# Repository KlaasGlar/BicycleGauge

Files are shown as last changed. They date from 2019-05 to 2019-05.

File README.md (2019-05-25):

# BicycleGauge

## Introduction

This project features an advanced computer for use on bicycles.
A microcontroller reads sensor data and sends it to a smartphone via bluetooth.

## Feature list

The following features are going to be integrated in the prototype:
- Magnetic switch for reading the revolution speed of the pedals
- Magnetic switch at the back wheel for reading the absolute speed
- Solar cell for recharging the computer's battery (Li-Ion AAA battery)
- Bluetooth module for communication with the smartphone
- Magnetic sensor for the reading the earth's magnetic field to calculate the slope when going up/downhill
- Analog sensor to read the battery charge status
- All parts are going to be waterproofed for outdoor use

## Content of this repository

The repository contains the following things:
- Schematic and PCB data for the main PCB
- Schematic and PCB data for the magnetic switches
- ~~CAD data for the housing of the main PCB~~
- ~~Code for programming the microcontroller~~
- ~~Code for the Android App to connect to the computer~~

**_The project is currently in development. New things are added little by little.
My plan is to have the prototype running by end of July 2019.
See the roadmap below for the current status._**

## Roadmap

- [X] <code>[##########>]&nbsp;100%</code> Creating the schematics for the main PCB
- [X] <code>[##########>]&nbsp;100%</code> Designing the main PCB
- [X] <code>[##########>]&nbsp;100%</code> Creating the schematics for the magnetic switches
- [X] <code>[##########>]&nbsp;100%</code> Designing the PCB for the magnetic switches
- [ ] <code>[###>_______]&nbsp;&nbsp;30%</code> Designing the housing (CAD)
- [ ] <code>[>__________]&nbsp;&nbsp;&nbsp;0%</code> Programming the microcontroller
- [ ] <code>[#>_________]&nbsp;&nbsp;10%</code> Programming the Android app

## Future ideas

- Voltage / current sensor to measure the power generated by the solar cell
- Smaller Battery if overall power consumption is measured to be sufficiently low

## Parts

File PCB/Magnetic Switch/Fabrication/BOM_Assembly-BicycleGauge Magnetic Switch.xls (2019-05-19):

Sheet: Assembly
ASSEMBLY |  |  |  |  |  | v1.0
 |  |  |  |  |  | 19.05.2019
 |  |  |  |  |  | 10:40:14
 |  |  | Bicycle Gauge Magnetic Switch
 | Project |  | BicycleGauge Magnetic Switch.PrjPcb
 | Drawn By |  | Sven Möller
 | Approved By |  | -
# |  | Quantity | Description | MPN | Designator
1 | ¨ | 1 | Diode, TVS, 3.3V, 4 Channel | 824013 | D1
2 | ¨ | 1 | Magnetic Sensor, SOT-23, Hall-Effect 3mT, Open-Drain, 2.5-5.5V | AH1806-W-7 | IC1
3 | ¨ | 2 | Connector, PTSM, SMD, 4 pol., Wire to Board | 1702474 | J1, J2

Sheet: Haken
¨
þ

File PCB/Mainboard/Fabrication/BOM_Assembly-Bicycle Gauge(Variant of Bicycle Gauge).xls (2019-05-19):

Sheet: Assembly
ASSEMBLY |  |  |  |  |  | v1.0.1
 |  |  |  |  |  | 19.05.2019
 |  |  |  |  |  | 10:30:37
 |  |  | Bicycle Gauge
 | Project |  | Bicycle Gauge.PrjPcb
 | Drawn By |  | Sven Möller
 | Approved By |  | -
# |  | Quantity | Description | MPN | Designator
1 | ¨ | 1 | Bluetooth module, Proteus-I, BT 4.2, AMB2621 | 2608011024000 | B1
2 | ¨ | 6 | Cap, 100n, 0603, X7R, 50V | CC0603KRX7R9BB104 | C1, C3, C6, C7, C16A, C16B
3 | ¨ | 1 | Cap, 1µ, 4x5.4mm, Aluminum Electrolyte, 35V | EEE-FC1V1R0R | C4
4 | ¨ | 2 | Cap, 18p, 0603, C0G, 50V | C0603C180J5GACTU | C8, C9
5 | ¨ | 2 | Cap, 1µ, 0805, 50V, X7R | GRM21BR71H105KA12L | C10, C11
6 | ¨ | 2 | Cap, 4.7µ, 0603, X5R, 10V | C0603C475M8PACTU | C12, C14
7 | ¨ | 2 | Cap, 10n, 0603, C0G, 25V | C0603C103J3GACTU | C13, C15
8 | ¨ | 1 | Diode, TVS, 3.3V, 4 Channel | 824013 | D1
9 | ¨ | 1 | MCU, TQFP-32, AVR-Mega 8-bit, 1.8-5.5V | ATmega328PB-AU | IC1
10 | ¨ | 1 | Magnetic Sensor, LGA-12, 1.9-3.6V, +/-1.6mT | LIS3MDLTR | IC2
11 | ¨ | 1 | Linear Regulator, SOT-23-5, 2.7V, Input 2.2-5.5V | TPS78227DDCR | IC3
12 | ¨ | 2 | MOSFET, SOT-883, p-channel, -20V, -0.5A, low leakage current | PMZ950UPEL | IC4, IC5
13 | ¨ | 1 | Energy Harvester / Boost Converter, VQFN-20 | BQ25505RGRR | IC6
14 | ¨ | 2 | Op-Amp, SOT-32, 1.7-5.5V, Rail-to-rail, Nanopower | OPA322SAIDBVR | IC7A, IC7B
15 | ¨ | 2 | MOSFET, SOT-883, n-channel, 20V, 0.6A, low leakage current | PMZ600UNEL | IC8A, IC8B
16 | ¨ | 1 | Connector, M8, SMD, 4-pin, Female | 1412228 | J1
17 | ¨ | 1 | Connector, PTSM, SMD, 2 pol., Wire to board | 1702473 | J2
18 | ¨ | 1 | Ind, 22µH, 0.51A, 3.8x3.8x1.65mm | 744031220 | L1
19 | ¨ | 2 | Res, 10R, 0603, 1%, 100mW, 50V | ERJ-3EKF10R0V | R1, R2
20 | ¨ | 7 | Res, 698k, 0603, 1%, 75V, 100mW | ERJ-3EKF6983V | R3, R4, R5, R10, R15A, R15B, R16
21 | ¨ | 1 | Res, 7.32M, 0603, 1%, 75V, 100mW | CRCW06037M32FKEA | R6
22 | ¨ | 2 | Res, 1.3M, 0603, 1%, 75V, 100mW | CRCW06031M30FKEA | R7, R12
23 | ¨ | 1 | Res, 5.62M, 0603, 1%, 75V, 100mW | CRCW06035M62FKEA | R8
24 | ¨ | 1 | Res, 6.98M, 0603, 1%, 75V, 100mW | CRCW06036M98FKEA | R9
25 | ¨ | 1 | Res, 4.7M, 0603, 1%, 75V, 100mW | CRCW06034M70FKEA | R11
26 | ¨ | 4 | Res, 330k, 0603, 0.1%, 25ppm, 75V, 100mW | ERA-3AEB334V | R13A, R13B, R14A, R14B
27 | ¨ | 1 | Housing, Panelmount, M8, Female | 1412504 | X1
28 | ¨ | 1 | Switch, SMD, DPDT, Slider WS-SLSV | 452403012014 | X2
29 | ¨ | 1 | Battery Holder, THT, 1xAAA | 1021 | X4
30 | ¨ | 1 | Solar Cell, 39.8mA@2.2V, 3.4V, 50x33x1.8mm | AM-5412CAR | X5
31 | ¨ | 1 | Nut, M10 | 1412508 | X6
32 | ¨ | 1 | Crystal, SMD, 7.3728MHz, 18pF | ABMM2-7.3728MHZ-E2-T | XT1

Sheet: Haken
¨
þ

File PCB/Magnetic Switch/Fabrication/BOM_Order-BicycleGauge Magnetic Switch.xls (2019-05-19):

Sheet: BOM
BILL OF MATERIALS |  |  |  |  |  |  |  | v1.0
 |  |  |  |  |  |  |  | 19.05.2019
 |  |  |  |  |  |  |  | 10:40:06
 |  |  | Bicycle Gauge Magnetic Switch
 | Project |  | BicycleGauge Magnetic Switch.PrjPcb |  |  | Production Quantity | 2
 | Drawn By |  | Sven Möller
 | Approved By |  | -
# |  | Qty | Description | Manufacturer | MPN | Digi-Key | Stock | Price | Farnell | Stock | Price | Mouser | Stock | Price | Supplier 4 | Supplier Part Number 4 | Stock | Price
1 | ¨ | 2 | Diode, TVS, 3.3V, 4 Channel | Würth Electronics | 824013 | 732-4466-1-ND | 23680 | 1.20 | 1825869 | 6162 | 0.00 | 710-824013 | 14221 | 1.20 | RSComponents | 7546222 | 585 | 0.00
2 | ¨ | 2 | Magnetic Sensor, SOT-23, Hall-Effect 3mT, Open-Drain, 2.5-5.5V | Diodes Inc. | AH1806-W-7 | AH1806-W-7DICT-ND | 26504 | 0.49 | - | 0 | 0.00 | 621-AH1806-W-7 | 43782 | 0.44 |  |  | 0 | 0.00
3 | ¨ | 4 | Connector, PTSM, SMD, 4 pol., Wire to Board | Phoenix Contact | 1702474 | 277-2338-1-ND | 1322 | 1.06 | - | 0 | 0.00 | 651-1702474 | 1334 | 1.07 | RSComponents | 804-5449 | 0 | 0.00

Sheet: Haken
¨ | #REF! | #REF!
þ | #REF! | #REF!
yes | #REF! | #REF!
no | #REF! | #REF!
 | #REF! | #REF!
 | #REF! | #REF!
 | #REF! | #REF!
 | #REF! | #REF!
 | #REF! | #REF!
 | #REF! | #REF!
 | #REF! | #REF!
 | #REF! | #REF!
 | #REF! | #REF!
 | #REF! | #REF!
 | #REF! | #REF!
 | #REF! | #REF!
 | #REF! | #REF!
 | #REF! | #REF!
 | #REF! | #REF!
 | #REF! | #REF!
 | #REF! | #REF!
 | #REF! | #REF!
 | #REF! | #REF!
 | #REF! | #REF!
 | #REF! | #REF!
 | #REF! | #REF!
 | #REF! | #REF!
 | #REF! | #REF!
 | #REF! | #REF!
 | #REF! | #REF!
 | #REF! | #REF!
 | #REF! | #REF!
 | #REF! | #REF!
 | #REF! | #REF!
 | #REF! | #REF!
 | #REF! | #REF!
 | #REF! | #REF!
 | #REF! | #REF!
 | #REF! | #REF!
 | #REF! | #REF!
 | #REF! | #REF!
 | #REF! | #REF!
 | #REF! | #REF!
 | #REF! | #REF!
 | #REF! | #REF!
 | #REF! | #REF!
 | #REF! | #REF!
 | #REF! | #REF!
 | #REF! | #REF!
 | #REF! | #REF!
 | #REF! | #REF!
 | #REF! | #REF!
 | #REF! | #REF!
 | #REF! | #REF!
 | #REF! | #REF!
 | #REF! | #REF!
 | #REF! | #REF!
 | #REF! | #REF!
 | #REF! | #REF!
 | #REF! | #REF!
 | #REF! | #REF!
 | #REF! | #REF!
 | #REF! | #REF!
 | #REF! | #REF!
 | #REF! | #REF!
 | #REF! | #REF!
 | #REF! | #REF!
 | #REF! | #REF!
 | #REF! | #REF!
 | #REF! | #REF!
 | #REF! | #REF!
 | #REF! | #REF!
 | #REF! | #REF!
 | #REF! | #REF!
 | #REF! | #REF!
 | #REF! | #REF!
 | #REF! | #REF!
 | #REF! | #REF!
 | #REF! | #REF!
 | #REF! | #REF!
 | #REF! | #REF!
 | #REF! | #REF!
 | #REF! | #REF!
 | #REF! | #REF!
 | #REF! | #REF!
 | #REF! | #REF!
 | #REF! | #REF!
 | #REF! | #REF!
 | #REF! | #REF!
 | #REF! | #REF!
 | #REF! | #REF!
 | #REF! | #REF!
 | #REF! | #REF!
 | #REF! | #REF!
 | #REF! | #REF!
 | #REF! | #REF!
 | #REF! | #REF!
 | #REF! | #REF!
 | #REF! | #REF!
 | #REF! | #REF!
 | #REF! | #REF!
 | #REF! | #REF!
 | #REF! | #REF!
 | #REF! | #REF!
 | #REF! | #REF!
 | #REF! | #REF!
 | #REF! | #REF!
 | #REF! | #REF!
 | #REF! | #REF!
 | #REF! | #REF!
 | #REF! | #REF!
 | #REF! | #REF!
 | #REF! | #REF!
 | #REF! | #REF!
 | #REF! | #REF!
 | #REF! | #REF!
 | #REF! | #REF!
 | #REF! | #REF!
 | #REF! | #REF!
 | #REF! | #REF!
 | #REF! | #REF!
 | #REF! | #REF!
 | #REF! | #REF!
 | #REF! | #REF!
 | #REF! | #REF!
 | #REF! | #REF!
 | #REF! | #REF!
 | #REF! | #REF!
 | #REF! | #REF!
 | #REF! | #REF!
 | #REF! | #REF!
 | #REF! | #REF!
 | #REF! | #REF!
 | #REF! | #REF!
 | #REF! | #REF!
 | #REF! | #REF!
 | #REF! | #REF!
 | #REF! | #REF!
 | #REF! | #REF!
 | #REF! | #REF!
 | #REF! | #REF!
 | #REF! | #REF!
 | #REF! | #REF!
 | #REF! | #REF!
 | #REF! | #REF!
 | #REF! | #REF!
 | #REF! | #REF!
 | #REF! | #REF!
 | #REF! | #REF!
 | #REF! | #REF!
 | #REF! | #REF!
 | #REF! | #REF!
 | #REF! | #REF!
 | #REF! | #REF!
 | #REF! | #REF!
 | #REF! | #REF!
 | #REF! | #REF!
 | #REF! | #REF!
 | #REF! | #REF!
 | #REF! | #REF!
 | #REF! | #REF!
 | #REF! | #REF!
 | #REF! | #REF!
 | #REF! | #REF!
 | #REF! | #REF!
 | #REF! | #REF!
 | #REF! | #REF!
 | #REF! | #REF!
 | #REF! | #REF!
 | #REF! | #REF!
 | #REF! | #REF!
 | #REF! | #REF!
 | #REF! | #REF!
 | #REF! | #REF!
 | #REF! | #REF!
 | #REF! | #REF!
 | #REF! | #REF!
 | #REF! | #REF!
 | #REF! | #REF!
 | #REF! | #REF!
 | #REF! | #REF!
 | #REF! | #REF!
 | #REF! | #REF!
 | #REF! | #REF!
 | #REF! | #REF!
 | #REF! | #REF!
 | #REF! | #REF!
 | #REF! | #REF!
 | #REF! | #REF!
 | #REF! | #REF!
 | #REF! | #REF!
 | #REF! | #REF!
 | #REF! | #REF!
 | #REF! | #REF!
 | #REF! | #REF!
 | #REF! | #REF!
 | #REF! | #REF!
 | #REF! | #REF!
 | #REF! | #REF!
 | #REF! | #REF!
 | #REF! | #REF!
 | #REF! | #REF!
 | #REF! | #REF!
 | #REF! | #REF!
 | #REF! | #REF!
 | #REF! | #REF!
 | #REF! | #REF!
 | #REF! | #REF!
 | #REF! | #REF!
 | #REF! | #REF!
 | #REF! | #REF!
 | #REF! | #REF!
 | #REF! | #REF!
 | #REF! | #REF!
 | #REF! | #REF!
 | #REF! | #REF!
 | #REF! | #REF!
 | #REF! | #REF!
 | #REF! | #REF!
 | #REF! | #REF!
 | #REF! | #REF!
 | #REF! | #REF!
 | #REF! | #REF!
 | #REF! | #REF!
 | #REF! | #REF!
 | #REF! | #REF!
 | #REF! | #REF!
 | #REF! | #REF!
 | #REF! | #REF!
 | #REF! | #REF!
 | #REF! | #REF!
 | #REF! | #REF!
 | #REF! | #REF!
 | #REF! | #REF!
 | #REF! | #REF!
 | #REF! | #REF!
 | #REF! | #REF!
 | #REF! | #REF!
 | #REF! | #REF!
 | #REF! | #REF!
 | #REF! | #REF!
 | #REF! | #REF!
 | #REF! | #REF!
 | #REF! | #REF!
 | #REF! | #REF!
 | #REF! | #REF!
 | #REF! | #REF!
 | #REF! | #REF!
 | #REF! | #REF!
 | #REF! | #REF!
 | #REF! | #REF!
 | #REF! | #REF!
 | #REF! | #REF!
 | #REF! | #REF!
 | #REF! | #REF!
 | #REF! | #REF!
 | #REF! | #REF!
 | #REF! | #REF!
 | #REF! | #REF!
 | #REF! | #REF!
 | #REF! | #REF!
 | #REF! | #REF!
 | #REF! | #REF!
 | #REF! | #REF!
 | #REF! | #REF!
 | #REF! | #REF!
 | #REF! | #REF!
 | #REF! | #REF!
 | #REF! | #REF!
 | #REF! | #REF!
 | #REF! | #REF!
 | #REF! | #REF!
 | #REF! | #REF!
 | #REF! | #REF!
 | #REF! | #REF!
 | #REF! | #REF!
 | #REF! | #REF!
 | #REF! | #REF!
 | #REF! | #REF!
 | #REF! | #REF!
 | #REF! | #REF!
 | #REF! | #REF!
 | #REF! | #REF!
 | #REF! | #REF!
 | #REF! | #REF!
 | #REF! | #REF!
 | #REF! | #REF!
 | #REF! | #REF!
 | #REF! | #REF!
 | #REF! | #REF!
 | #REF! | #REF!
 | #REF! | #REF!
 | #REF! | #REF!
 | #REF! | #REF!
 | #REF! | #REF!
 | #REF! | #REF!
 | #REF! | #REF!
 | #REF! | #REF!
 | #REF! | #REF!
 | #REF! | #REF!
 | #REF! | #REF!
 | #REF! | #REF!
 | #REF! | #REF!
 | #REF! | #REF!
 | #REF! | #REF!
 | #REF! | #REF!
 | #REF! | #REF!
 | #REF! | #REF!
 | #REF! | #REF!
 | #REF! | #REF!
 | #REF! | #REF!
 | #REF! | #REF!
 | #REF! | #REF!
 | #REF! | #REF!
 | #REF! | #REF!
 | #REF! | #REF!
 | #REF! | #REF!
 | #REF! | #REF!
 | #REF! | #REF!
 | #REF! | #REF!
 | #REF! | #REF!
 | #REF! | #REF!
 | #REF! | #REF!
 | #REF! | #REF!
 | #REF! | #REF!
 | #REF! | #REF!
 | #REF! | #REF!
 | #REF! | #REF!
 | #REF! | #REF!
 | #REF! | #REF!
 | #REF! | #REF!
 | #REF! | #REF!
 | #REF! | #REF!
 | #REF! | #REF!
 | #REF! | #REF!
 | #REF! | #REF!
 | #REF! | #REF!
 | #REF! | #REF!
 | #REF! | #REF!
 | #REF! | #REF!
 | #REF! | #REF!
 | #REF! | #REF!
 | #REF! | #REF!
 | #REF! | #REF!
 | #REF! | #REF!
 | #REF! | #REF!
 | #REF! | #REF!
 | #REF! | #REF!
 | #REF! | #REF!
 | #REF! | #REF!
 | #REF! | #REF!
 | #REF! | #REF!
 | #REF! | #REF!
 | #REF! | #REF!
 | #REF! | #REF!
 | #REF! | #REF!
 | #REF! | #REF!
 | #REF! | #REF!
 | #REF! | #REF!
 | #REF! | #REF!
 | #REF! | #REF!
 | #REF! | #REF!
 | #REF! | #REF!
 | #REF! | #REF!
 | #REF! | #REF!
 | #REF! | #REF!
 | #REF! | #REF!
 | #REF! | #REF!
 | #REF! | #REF!
 | #REF! | #REF!
 | #REF! | #REF!
 | #REF! | #REF!
 | #REF! | #REF!
 | #REF! | #REF!
 | #REF! | #REF!
 | #REF! | #REF!
 | #REF! | #REF!
 | #REF! | #REF!
 | #REF! | #REF!
 | #REF! | #REF!
 | #REF! | #REF!
 | #REF! | #REF!
 | #REF! | #REF!
 | #REF! | #REF!
 | #REF! | #REF!
 | #REF! | #REF!
 | #REF! | #REF!
 | #REF! | #REF!
 | #REF! | #REF!
 | #REF! | #REF!
 | #REF! | #REF!
 | #REF! | #REF!
 | #REF! | #REF!
 | #REF! | #REF!
 | #REF! | #REF!
 | #REF! | #REF!
 | #REF! | #REF!
 | #REF! | #REF!
 | #REF! | #REF!
 | #REF! | #REF!
 | #REF! | #REF!
 | #REF! | #REF!
 | #REF! | #REF!
 | #REF! | #REF!
 | #REF! | #REF!
 | #REF! | #REF!
 | #REF! | #REF!
 | #REF! | #REF!
 | #REF! | #REF!
 | #REF! | #REF!
 | #REF! | #REF!
 | #REF! | #REF!
 | #REF! | #REF!
 | #REF! | #REF!
 | #REF! | #REF!
 | #REF! | #REF!
 | #REF! | #REF!
 | #REF! | #REF!
 | #REF! | #REF!
 | #REF! | #REF!
 | #REF! | #REF!
 | #REF! | #REF!
 | #REF! | #REF!
 | #REF! | #REF!
 | #REF! | #REF!
 | #REF! | #REF!
 | #REF! | #REF!
 | #REF! | #REF!
 | #REF! | #REF!
 | #REF! | #REF!
 | #REF! | #REF!
 | #REF! | #REF!
 | #REF! | #REF!
 | #REF! | #REF!
 | #REF! | #REF!
 | #REF! | #REF!
 | #REF! | #REF!
 | #REF! | #REF!
 | #REF! | #REF!
 | #REF! | #REF!
 | #REF! | #REF!
 | #REF! | #REF!
 | #REF! | #REF!
 | #REF! | #REF!
 | #REF! | #REF!
 | #REF! | #REF!
 | #REF! | #REF!
 | #REF! | #REF!
 | #REF! | #REF!
 | #REF! | #REF!
 | #REF! | #REF!
 | #REF! | #REF!
 | #REF! | #REF!
 | #REF! | #REF!
 | #REF! | #REF!
 | #REF! | #REF!
 | #REF! | #REF!
 | #REF! | #REF!
 | #REF! | #REF!
 | #REF! | #REF!
 | #REF! | #REF!
 | #REF! | #REF!
 | #REF! | #REF!
 | #REF! | #REF!
 | #REF! | #REF!
 | #REF! | #REF!
 | #REF! | #REF!
 | #REF! | #REF!
 | #REF! | #REF!
 | #REF! | #REF!
 | #REF! | #REF!
 | #REF! | #REF!
 | #REF! | #REF!
 | #REF! | #REF!
 | #REF! | #REF!
 | #REF! | #REF!
 | #REF! | #REF!
 | #REF! | #REF!
 | #REF! | #REF!
 | #REF! | #REF!
 | #REF! | #REF!
 | #REF! | #REF!
 | #REF! | #REF!
 | #REF! | #REF!
 | #REF! | #REF!
 | #REF! | #REF!
 | #REF! | #REF!
 | #REF! | #REF!
 | #REF! | #REF!
 | #REF! | #REF!
 | #REF! | #REF!
 | #REF! | #REF!
 | #REF! | #REF!
 | #REF! | #REF!
 | #REF! | #REF!
 | #REF! | #REF!
 | #REF! | #REF!
 | #REF! | #REF!
 | #REF! | #REF!
 | #REF! | #REF!
 | #REF! | #REF!
 | #REF! | #REF!
 | #REF! | #REF!
 | #REF! | #REF!
 | #REF! | #REF!
 | #REF! | #REF!
 | #REF! | #REF!
 | #REF! | #REF!
 | #REF! | #REF!
 | #REF! | #REF!
 | #REF! | #REF!
 | #REF! | #REF!
 | #REF! | #REF!
 | #REF! | #REF!
 | #REF! | #REF!
 | #REF! | #REF!
 | #REF! | #REF!
 | #REF! | #REF!
 | #REF! | #REF!
 | #REF! | #REF!
 | #REF! | #REF!
 | #REF! | #REF!
 | #REF! | #REF!
 | #REF! | #REF!
 | #REF! | #REF!
 | #REF! | #REF!
 | #REF! | #REF!
 | #REF! | #REF!
 | #REF! | #REF!
 | #REF! | #REF!
 | #REF! | #REF!
 | #REF! | #REF!
 | #REF! | #REF!
 | #REF! | #REF!
 | #REF! | #REF!
 | #REF! | #REF!
 | #REF! | #REF!
 | #REF! | #REF!
 | #REF! | #REF!
 | #REF! | #REF!
 | #REF! | #REF!
 | #REF! | #REF!
 | #REF! | #REF!
 | #REF! | #REF!
 | #REF! | #REF!
 | #REF! | #REF!
 | #REF! | #REF!
 | #REF! | #REF!
 | #REF! | #REF!
 | #REF! | #REF!
 | #REF! | #REF!
 | #REF! | #REF!
 | #REF! | #REF!
 | #REF! | #REF!
 | #REF! | #REF!
 | #REF! | #REF!
 | #REF! | #REF!
 | #REF! | #REF!
 | #REF! | #REF!
 | #REF! | #REF!
 | #REF! | #REF!
 | #REF! | #REF!
 | #REF! | #REF!
 | #REF! | #REF!
 | #REF! | #REF!
 | #REF! | #REF!
 | #REF! | #REF!
 | #REF! | #REF!
 | #REF! | #REF!
 | #REF! | #REF!
 | #REF! | #REF!
 | #REF! | #REF!
 | #REF! | #REF!
 | #REF! | #REF!
 | #REF! | #REF!
 | #REF! | #REF!
 | #REF! | #REF!
 | #REF! | #REF!
 | #REF! | #REF!
 | #REF! | #REF!
 | #REF! | #REF!
 | #REF! | #REF!
 | #REF! | #REF!
 | #REF! | #REF!
 | #REF! | #REF!
 | #REF! | #REF!
 | #REF! | #REF!
 | #REF! | #REF!
 | #REF! | #REF!
 | #REF! | #REF!
 | #REF! | #REF!
 | #REF! | #REF!
 | #REF! | #REF!
 | #REF! | #REF!
 | #REF! | #REF!
 | #REF! | #REF!
 | #REF! | #REF!
 | #REF! | #REF!
 | #REF! | #REF!
 | #REF! | #REF!
 | #REF! | #REF!
 | #REF! | #REF!
 | #REF! | #REF!
 | #REF! | #REF!
 | #REF! | #REF!
 | #REF! | #REF!
 | #REF! | #REF!
 | #REF! | #REF!
 | #REF! | #REF!
 | #REF! | #REF!
 | #REF! | #REF!
 | #REF! | #REF!
 | #REF! | #REF!
 | #REF! | #REF!
 | #REF! | #REF!
 | #REF! | #REF!
 | #REF! | #REF!
 | #REF! | #REF!
 | #REF! | #REF!
 | #REF! | #REF!
 | #REF! | #REF!
 | #REF! | #REF!
 | #REF! | #REF!
 | #REF! | #REF!
 | #REF! | #REF!
 | #REF! | #REF!
 | #REF! | #REF!
 | #REF! | #REF!
 | #REF! | #REF!
 | #REF! | #REF!
 | #REF! | #REF!
 | #REF! | #REF!
 | #REF! | #REF!
 | #REF! | #REF!
 | #REF! | #REF!
 | #REF! | #REF!
 | #REF! | #REF!
 | #REF! | #REF!
 | #REF! | #REF!
 | #REF! | #REF!
 | #REF! | #REF!
 | #REF! | #REF!
 | #REF! | #REF!
 | #REF! | #REF!
 | #REF! | #REF!
 | #REF! | #REF!
 | #REF! | #REF!
 | #REF! | #REF!
 | #REF! | #REF!
 | #REF! | #REF!
 | #REF! | #REF!
 | #REF! | #REF!
 | #REF! | #REF!
 | #REF! | #REF!
 | #REF! | #REF!
 | #REF! | #REF!
 | #REF! | #REF!
 | #REF! | #REF!
 | #REF! | #REF!
 | #REF! | #REF!
 | #REF! | #REF!
 | #REF! | #REF!
 | #REF! | #REF!
 | #REF! | #REF!
 | #REF! | #REF!
 | #REF! | #REF!
 | #REF! | #REF!
 | #REF! | #REF!
 | #REF! | #REF!
 | #REF! | #REF!
 | #REF! | #REF!
 | #REF! | #REF!
 | #REF! | #REF!
 | #REF! | #REF!
 | #REF! | #REF!
 | #REF! | #REF!
 | #REF! | #REF!
 | #REF! | #REF!
 | #REF! | #REF!
 | #REF! | #REF!
 | #REF! | #REF!
 | #REF! | #REF!
 | #REF! | #REF!
 | #REF! | #REF!
 | #REF! | #REF!
 | #REF! | #REF!
 | #REF! | #REF!
 | #REF! | #REF!
 | #REF! | #REF!
 | #REF! | #REF!
 | #REF! | #REF!
 | #REF! | #REF!
 | #REF! | #REF!
 | #REF! | #REF!
 | #REF! | #REF!
 | #REF! | #REF!
 | #REF! | #REF!
 | #REF! | #REF!
 | #REF! | #REF!
 | #REF! | #REF!
 | #REF! | #REF!
 | #REF! | #REF!
 | #REF! | #REF!
 | #REF! | #REF!
 | #REF! | #REF!
 | #REF! | #REF!
 | #REF! | #REF!
 | #REF! | #REF!
 | #REF! | #REF!
 | #REF! | #REF!
 | #REF! | #REF!
 | #REF! | #REF!
 | #REF! | #REF!
 | #REF! | #REF!
 | #REF! | #REF!
 | #REF! | #REF!
 | #REF! | #REF!
 | #REF! | #REF!
 | #REF! | #REF!
 | #REF! | #REF!
 | #REF! | #REF!
 | #REF! | #REF!
 | #REF! | #REF!
 | #REF! | #REF!
 | #REF! | #REF!
 | #REF! | #REF!
 | #REF! | #REF!
 | #REF! | #REF!
 | #REF! | #REF!
 | #REF! | #REF!
 | #REF! | #REF!
 | #REF! | #REF!
 | #REF! | #REF!
 | #REF! | #REF!
 | #REF! | #REF!
 | #REF! | #REF!
 | #REF! | #REF!
 | #REF! | #REF!
 | #REF! | #REF!
 | #REF! | #REF!
 | #REF! | #REF!
 | #REF! | #REF!
 | #REF! | #REF!
 | #REF! | #REF!
 | #REF! | #REF!
 | #REF! | #REF!
 | #REF! | #REF!
 | #REF! | #REF!
 | #REF! | #REF!
 | #REF! | #REF!
 | #REF! | #REF!
 | #REF! | #REF!
 | #REF! | #REF!
 | #REF! | #REF!
 | #REF! | #REF!
 | #REF! | #REF!
 | #REF! | #REF!
 | #REF! | #REF!
 | #REF! | #REF!
 | #REF! | #REF!
 | #REF! | #REF!
 | #REF! | #REF!
 | #REF! | #REF!
 | #REF! | #REF!
 | #REF! | #REF!
 | #REF! | #REF!
 | #REF! | #REF!
 | #REF! | #REF!
 | #REF! | #REF!
 | #REF! | #REF!
 | #REF! | #REF!
 | #REF! | #REF!
 | #REF! | #REF!
 | #REF! | #REF!
 | #REF! | #REF!
 | #REF! | #REF!
 | #REF! | #REF!
 | #REF! | #REF!
 | #REF! | #REF!
 | #REF! | #REF!
 | #REF! | #REF!
 | #REF! | #REF!
 | #REF! | #REF!
 | #REF! | #REF!
 | #REF! | #REF!
 | #REF! | #REF!
 | #REF! | #REF!
 | #REF! | #REF!
 | #REF! | #REF!
 | #REF! | #REF!
 | #REF! | #REF!
 | #REF! | #REF!
 | #REF! | #REF!
 | #REF! | #REF!
 | #REF! | #REF!
 | #REF! | #REF!
 | #REF! | #REF!
 | #REF! | #REF!
 | #REF! | #REF!
 | #REF! | #REF!
 | #REF! | #REF!
 | #REF! | #REF!
 | #REF! | #REF!
 | #REF! | #REF!
 | #REF! | #REF!
 | #REF! | #REF!
 | #REF! | #REF!
 | #REF! | #REF!
 | #REF! | #REF!
 | #REF! | #REF!
 | #REF! | #REF!
 | #REF! | #REF!
 | #REF! | #REF!
 | #REF! | #REF!
 | #REF! | #REF!
 | #REF! | #REF!
 | #REF! | #REF!
 | #REF! | #REF!
 | #REF! | #REF!
 | #REF! | #REF!
 | #REF! | #REF!
 | #REF! | #REF!
 | #REF! | #REF!
 | #REF! | #REF!
 | #REF! | #REF!
 | #REF! | #REF!
 | #REF! | #REF!
 | #REF! | #REF!
 | #REF! | #REF!
 | #REF! | #REF!
 | #REF! | #REF!
 | #REF! | #REF!
 | #REF! | #REF!
 | #REF! | #REF!
 | #REF! | #REF!
 | #REF! | #REF!
 | #REF! | #REF!
 | #REF! | #REF!
 | #REF! | #REF!
 | #REF! | #REF!
 | #REF! | #REF!
 | #REF! | #REF!
 | #REF! | #REF!
 | #REF! | #REF!
 | #REF! | #REF!
 | #REF! | #REF!
 | #REF! | #REF!
 | #REF! | #REF!
 | #REF! | #REF!
 | #REF! | #REF!
 | #REF! | #REF!
 | #REF! | #REF!
 | #REF! | #REF!
 | #REF! | #REF!
 | #REF! | #REF!
 | #REF! | #REF!
 | #REF! | #REF!
 | #REF! | #REF!
 | #REF! | #REF!
 | #REF! | #REF!
 | #REF! | #REF!
 | #REF! | #REF!
 | #REF! | #REF!
 | #REF! | #REF!
 | #REF! | #REF!
 | #REF! | #REF!
 | #REF! | #REF!
 | #REF! | #REF!
 | #REF! | #REF!
 | #REF! | #REF!
 | #REF! | #REF!
 | #REF! | #REF!
 | #REF! | #REF!
 | #REF! | #REF!
 | #REF! | #REF!
 | #REF! | #REF!
 | #REF! | #REF!
 | #REF! | #REF!
 | #REF! | #REF!
 | #REF! | #REF!
 | #REF! | #REF!
 | #REF! | #REF!
 | #REF! | #REF!
 | #REF! | #REF!
 | #REF! | #REF!
 | #REF! | #REF!
 | #REF! | #REF!
 | #REF! | #REF!
 | #REF! | #REF!
 | #REF! | #REF!
 | #REF! | #REF!
 | #REF! | #REF!
 | #REF! | #REF!
 | #REF! | #REF!
 | #REF! | #REF!
 | #REF! | #REF!
 | #REF! | #REF!
 | #REF! | #REF!
 | #REF! | #REF!
 | #REF! | #REF!
 | #REF! | #REF!
 | #REF! | #REF!
 | #REF! | #REF!
 | #REF! | #REF!
 | #REF! | #REF!
 | #REF! | #REF!
 | #REF! | #REF!
 | #REF! | #REF!
 | #REF! | #REF!
 | #REF! | #REF!
 | #REF! | #REF!
 | #REF! | #REF!
 | #REF! | #REF!
 | #REF! | #REF!
 | #REF! | #REF!
 | #REF! | #REF!
 | #REF! | #REF!
 | #REF! | #REF!
 | #REF! | #REF!
 | #REF! | #REF!
 | #REF! | #REF!
 | #REF! | #REF!
 | #REF! | #REF!
 | #REF! | #REF!
 | #REF! | #REF!
 | #REF! | #REF!
 | #REF! | #REF!
 | #REF! | #REF!
 | #REF! | #REF!
 | #REF! | #REF!
 | #REF! | #REF!
 | #REF! | #REF!
 | #REF! | #REF!
 | #REF! | #REF!
 | #REF! | #REF!
 | #REF! | #REF!
 | #REF! | #REF!
 | #REF! | #REF!
 | #REF! | #REF!
 | #REF! | #REF!
 | #REF! | #REF!
 | #REF! | #REF!
 | #REF! | #REF!
 | #REF! | #REF!
 | #REF! | #REF!
 | #REF! | #REF!
 | #REF! | #REF!
 | #REF! | #REF!
 | #REF! | #REF!
 | #REF! | #REF!
 | #REF! | #REF!
 | #REF! | #REF!
 | #REF! | #REF!
 | #REF! | #REF!
 | #REF! | #REF!
 | #REF! | #REF!
 | #REF! | #REF!
 | #REF! | #REF!
 | #REF! | #REF!
 | #REF! | #REF!
 | #REF! | #REF!
 | #REF! | #REF!
 | #REF! | #REF!
 | #REF! | #REF!
 | #REF! | #REF!
 | #REF! | #REF!
 | #REF! | #REF!
 | #REF! | #REF!
 | #REF! | #REF!
 | #REF! | #REF!
 | #REF! | #REF!
 | #REF! | #REF!
 | #REF! | #REF!
 | #REF! | #REF!
 | #REF! | #REF!
 | #REF! | #REF!
 | #REF! | #REF!
 | #REF! | #REF!
 | #REF! | #REF!
 | #REF! | #REF!
 | #REF! | #REF!
 | #REF! | #REF!
 | #REF! | #REF!
 | #REF! | #REF!
 | #REF! | #REF!
 | #REF! | #REF!
 | #REF! | #REF!
 | #REF! | #REF!
 | #REF! | #REF!
 | #REF! | #REF!
 | #REF! | #REF!
 | #REF! | #REF!
 | #REF! | #REF!
 | #REF! | #REF!
 | #REF! | #REF!
 | #REF! | #REF!
 | #REF! | #REF!
 | #REF! | #REF!
 | #REF! | #REF!
 | #REF! | #REF!

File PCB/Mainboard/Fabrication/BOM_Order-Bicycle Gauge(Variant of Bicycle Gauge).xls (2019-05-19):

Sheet: BOM
BILL OF MATERIALS |  |  |  |  |  |  |  | v1.0.1
 |  |  |  |  |  |  |  | 19.05.2019
 |  |  |  |  |  |  |  | 10:29:25
 |  |  | Bicycle Gauge
 | Project |  | Bicycle Gauge.PrjPcb |  |  | Production Quantity | 1
 | Drawn By |  | Sven Möller
 | Approved By |  | -
# |  | Qty | Description | Manufacturer | MPN | Digi-Key | Stock | Price | Farnell | Stock | Price | Mouser | Stock | Price | Supplier 4 | Supplier Part Number 4 | Stock | Price
1 | ¨ | 1 | Bluetooth module, Proteus-I, BT 4.2, AMB2621 | Würth Elektronik | 2608011024000 | 1917-1014-1-ND | 1014 | 16.00 | 2917636 | 37 | 15.10 |  | 0 | 0.00 |  |  | 0 | 0.00
2 | ¨ | 6 | Cap, 100n, 0603, X7R, 50V | Yageo | CC0603KRX7R9BB104 | 311-1344-1-ND | 20629964 | 0.12 | - | 0 | 0.00 | 603-CC603KRX7R9BB104 | 132954493 | 0.11 |  |  | 0 | 0.00
3 | ¨ | 1 | Cap, 1µ, 4x5.4mm, Aluminum Electrolyte, 35V | Panasonic | EEE-FC1V1R0R | PCE4024CT-ND | 142308 | 0.34 | 2357339 | 4330 | 0.00 | 667-EEE-FC1V1R0R | 10377 | 0.34 |  |  | 0 | 0.00
4 | ¨ | 2 | Cap, 18p, 0603, C0G, 50V | Kemet | C0603C180J5GACTU | 399-1052-1-ND | 112419 | 0.10 | 1414620 | 0 | 0.00 | 80-C0603C180J5G | 158624 | 0.10 |  |  | 0 | 0.00
5 | ¨ | 2 | Cap, 1µ, 0805, 50V, X7R | Murata | GRM21BR71H105KA12L | 490-4736-1-ND | 0 | 0.00 | 1735541 | 0 | 0.00 | 81-GRM21BR71H105KA2L | 0 | 0.00 |  |  | 0 | 0.00
6 | ¨ | 2 | Cap, 4.7µ, 0603, X5R, 10V | Kemet | C0603C475M8PACTU | 399-9100-1-ND | 256073 | 0.33 | 2112834 | 0 | 0.00 | 80-C0603C475M8P | 48946 | 0.87 |  |  | 0 | 0.00
7 | ¨ | 2 | Cap, 10n, 0603, C0G, 25V | Kemet | C0603C103J3GACTU | 399-7838-1-ND | 326575 | 0.45 | 1457729 | 13434 | 0.00 | 80-C0603C103J3G | 864 | 0.37 |  |  | 0 | 0.00
8 | ¨ | 1 | Diode, TVS, 3.3V, 4 Channel | Würth Electronics | 824013 | 732-4466-1-ND | 23680 | 1.20 | 1825869 | 6162 | 0.00 | 710-824013 | 14221 | 1.20 | RSComponents | 7546222 | 585 | 0.00
9 | ¨ | 1 | MCU, TQFP-32, AVR-Mega 8-bit, 1.8-5.5V | Microchip | ATmega328PB-AU | ATMEGA328PB-AU-ND | 4309 | 1.38 | 2523203 | 5668 | 1.05 | 556-ATMEGA328PB-AU | 9842 | 1.38 | RSComponents | 1468928 | 570 | 0.00
10 | ¨ | 1 | Magnetic Sensor, LGA-12, 1.9-3.6V, +/-1.6mT | ST Microelectronics | LIS3MDLTR | 497-13892-1-ND | 17520 | 1.67 | 2433083 | 9041 | 1.23 | 511-LIS3MDLTR | 60887 | 1.62 | RSComponents | 9172725 | 390 | 0.00
11 | ¨ | 1 | Linear Regulator, SOT-23-5, 2.7V, Input 2.2-5.5V | Texas Instruments | TPS78227DDCR | 296-23825-1-ND | 28237 | 0.83 | 2352270 | 274 | 0.717 | 595-TPS78227DDCR | 10402 | 0.81 | RSComponents | 8175436 | 0 | 0.00
12 | ¨ | 2 | MOSFET, SOT-883, p-channel, -20V, -0.5A, low leakage current | Nexperia | PMZ950UPEL | 1727-2599-1-ND | 6022 | 0.59 | 2673080 | 5632 | 0.00 | 771-PMZ950UPELYL | 6180 | 0.47 |  |  | 0 | 0.00
13 | ¨ | 1 | Energy Harvester / Boost Converter, VQFN-20 | Texas Instruments | BQ25505RGRR | 296-37078-1-ND | 6550 | 5.40 | - | 0 | 0.00 | 595-BQ25505RGRR | 3014 | 5.24 |  |  | 0 | 0.00
14 | ¨ | 2 | Op-Amp, SOT-32, 1.7-5.5V, Rail-to-rail, Nanopower | Texas Instruments | OPA322SAIDBVR | 296-40465-1-ND | 4896 | 1.77 | - | 0 | 0.00 | 595-OPA322SAIDBVR | 2639 | 1.71 |  |  | 0 | 0.00
15 | ¨ | 2 | MOSFET, SOT-883, n-channel, 20V, 0.6A, low leakage current | Nexperia | PMZ600UNEL | 1727-2598-1-ND | 10617 | 0.59 | 2673079 | 0 | 0.00 | 771-PMZ600UNELYL | 14722 | 0.47 |  |  | 0 | 0.00
16 | ¨ | 1 | Connector, M8, SMD, 4-pin, Female | Phoenix Contact | 1412228 | 1412228-ND | 0 | 0.00 | - | 0 | 0.00 | 651-1412228 | 84 | 4.28 |  |  | 0 | 0.00
17 | ¨ | 1 | Connector, PTSM, SMD, 2 pol., Wire to board | Phoenix Contact | 1702473 | 277-2337-1-ND | 7306 | 0.72 | 1793797 | 326 | 1.45 | 651-1702473 | 18793 | 0.73 |  |  | 0 | 0.00
18 | ¨ | 1 | Ind, 22µH, 0.51A, 3.8x3.8x1.65mm | Würth Elektronik | 744031220 | 732-1012-1-ND | 10003 | 1.43 | 1890602 | 2504 | 1.22 | 710-744031220 | 2212 | 1.43 | RSComponents | 617-0903 | 79 | 0.00
19 | ¨ | 2 | Res, 10R, 0603, 1%, 100mW, 50V | Panasonic | ERJ-3EKF10R0V | P10.0HCT-ND | 1735861 | 0.10 | 2302958 | 0 | 0.00 | 667-ERJ-3EKF10R0V | 674362 | 0.27 |  |  | 0 | 0.00
20 | ¨ | 7 | Res, 698k, 0603, 1%, 75V, 100mW | Panasonic Electronic Components | ERJ-3EKF6983V | P698KHCT-ND | 111542 | 0.10 | 2303307 | 9540 | 0.00 | 667-ERJ-3EKF6983V | 51841 | 0.27 |  |  | 0 | 0.00
21 | ¨ | 1 | Res, 7.32M, 0603, 1%, 75V, 100mW | Vishay Dale | CRCW06037M32FKEA | 541-7.32MHCT-ND | 19466 | 0.10 | 2138713 | 0 | 0.00 | 71-CRCW06037M32FKEA | 15522 | 0.10 |  |  | 0 | 0.00
22 | ¨ | 2 | Res, 1.3M, 0603, 1%, 75V, 100mW | Vishay Dale | CRCW06031M30FKEA | 541-1.30MHCT-ND | 19743 | 0.10 | 2138620 | 8251 | 0.00 | 71-CRCW06031M30FKEA | 0 | 0.10 |  |  | 0 | 0.00
23 | ¨ | 1 | Res, 5.62M, 0603, 1%, 75V, 100mW | Vishay Dale | CRCW06035M62FKEA | 541-5.62MHCT-ND | 64867 | 0.10 | 2138698 | 2990 | 0.00 | 71-CRCW06035M62FKEA | 6784 | 0.10 |  |  | 0 | 0.00
24 | ¨ | 1 | Res, 6.98M, 0603, 1%, 75V, 100mW | Vishay Dale | CRCW06036M98FKEA | 541-6.98MHCT-ND | 9350 | 0.10 | 2138710 | 13954 | 0.00 | 71-CRCW06036M98FKEA | 6498 | 0.10 |  |  | 0 | 0.00
25 | ¨ | 1 | Res, 4.7M, 0603, 1%, 75V, 100mW | Vishay Dale | CRCW06034M70FKEA | 541-4.70MHCT-ND | 1933 | 0.10 | 2138688 | 14020 | 0.00 | 71-CRCW0603-4.7M-E3 | 0 | 0.10 |  |  | 0 | 0.00
26 | ¨ | 4 | Res, 330k, 0603, 0.1%, 25ppm, 75V, 100mW | Panasonic Electronic Components | ERA-3AEB334V | P330KDBCT-ND | 13113 | 0.35 | 1577639 | 6246 | 0.00 | 667-ERA-3AEB334V | 59035 | 0.63 |  |  | 0 | 0.00
27 | ¨ | 1 | Housing, Panelmount, M8, Female | Phoenix Contact | 1412504 | 277-10310-ND | 86 | 9.68 | - | 0 | 0.00 | 651-1412504 | 63 | 4.49 |  |  | 0 | 0.00
28 | ¨ | 1 | Switch, SMD, DPDT, Slider WS-SLSV | Würth Elektronik | 452403012014 | 732-10145-1-ND | 3417 | 2.51 | - | 0 | 0.00 | 710-452403012014 | 1845 | 2.51 |  |  | 0 | 0.00
29 | ¨ | 1 | Battery Holder, THT, 1xAAA | Keystone Electronics | 1021 | 36-1021-ND | 811 | 1.88 | - | 0 | 0.00 | 534-1021 | 0 | 1.55 | Conrad | 1555480 | 101 | 2.84
30 | ¨ | 1 | Solar Cell, 39.8mA@2.2V, 3.4V, 50x33x1.8mm | Panasonic BSG | AM-5412CAR | 869-1007-ND | 128 | 8.02 | - | 0 | 0.00 | 658-AM-5412CAR | 24 | 9.78 |  |  | 0 | 0.00
31 | ¨ | 1 | Nut, M10 | Phoenix Contact | 1412508 | 277-10312-ND | 364 | 1.60 | - | 0 | 0.00 | 651-1412508 | 171 | 0.74 |  |  | 0 | 0.00
32 | ¨ | 1 | Crystal, SMD, 7.3728MHz, 18pF | Abracon | ABMM2-7.3728MHZ-E2-T | 535-10157-1-ND | 17505 | 0.97 | 2467857 | 2029 | 0.828 | 815-ABMM2-7.3-E2-T | 9244 | 0.94 | RSComponents | 1712788 | 0 | 0.00

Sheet: Haken
¨ | #REF! | #REF!
þ | #REF! | #REF!
yes | #REF! | #REF!
no | #REF! | #REF!
 | #REF! | #REF!
 | #REF! | #REF!
 | #REF! | #REF!
 | #REF! | #REF!
 | #REF! | #REF!
 | #REF! | #REF!
 | #REF! | #REF!
 | #REF! | #REF!
 | #REF! | #REF!
 | #REF! | #REF!
 | #REF! | #REF!
 | #REF! | #REF!
 | #REF! | #REF!
 | #REF! | #REF!
 | #REF! | #REF!
 | #REF! | #REF!
 | #REF! | #REF!
 | #REF! | #REF!
 | #REF! | #REF!
 | #REF! | #REF!
 | #REF! | #REF!
 | #REF! | #REF!
 | #REF! | #REF!
 | #REF! | #REF!
 | #REF! | #REF!
 | #REF! | #REF!
 | #REF! | #REF!
 | #REF! | #REF!
 | #REF! | #REF!
 | #REF! | #REF!
 | #REF! | #REF!
 | #REF! | #REF!
 | #REF! | #REF!
 | #REF! | #REF!
 | #REF! | #REF!
 | #REF! | #REF!
 | #REF! | #REF!
 | #REF! | #REF!
 | #REF! | #REF!
 | #REF! | #REF!
 | #REF! | #REF!
 | #REF! | #REF!
 | #REF! | #REF!
 | #REF! | #REF!
 | #REF! | #REF!
 | #REF! | #REF!
 | #REF! | #REF!
 | #REF! | #REF!
 | #REF! | #REF!
 | #REF! | #REF!
 | #REF! | #REF!
 | #REF! | #REF!
 | #REF! | #REF!
 | #REF! | #REF!
 | #REF! | #REF!
 | #REF! | #REF!
 | #REF! | #REF!
 | #REF! | #REF!
 | #REF! | #REF!
 | #REF! | #REF!
 | #REF! | #REF!
 | #REF! | #REF!
 | #REF! | #REF!
 | #REF! | #REF!
 | #REF! | #REF!
 | #REF! | #REF!
 | #REF! | #REF!
 | #REF! | #REF!
 | #REF! | #REF!
 | #REF! | #REF!
 | #REF! | #REF!
 | #REF! | #REF!
 | #REF! | #REF!
 | #REF! | #REF!
 | #REF! | #REF!
 | #REF! | #REF!
 | #REF! | #REF!
 | #REF! | #REF!
 | #REF! | #REF!
 | #REF! | #REF!
 | #REF! | #REF!
 | #REF! | #REF!
 | #REF! | #REF!
 | #REF! | #REF!
 | #REF! | #REF!
 | #REF! | #REF!
 | #REF! | #REF!
 | #REF! | #REF!
 | #REF! | #REF!
 | #REF! | #REF!
 | #REF! | #REF!
 | #REF! | #REF!
 | #REF! | #REF!
 | #REF! | #REF!
 | #REF! | #REF!
 | #REF! | #REF!
 | #REF! | #REF!
 | #REF! | #REF!
 | #REF! | #REF!
 | #REF! | #REF!
 | #REF! | #REF!
 | #REF! | #REF!
 | #REF! | #REF!
 | #REF! | #REF!
 | #REF! | #REF!
 | #REF! | #REF!
 | #REF! | #REF!
 | #REF! | #REF!
 | #REF! | #REF!
 | #REF! | #REF!
 | #REF! | #REF!
 | #REF! | #REF!
 | #REF! | #REF!
 | #REF! | #REF!
 | #REF! | #REF!
 | #REF! | #REF!
 | #REF! | #REF!
 | #REF! | #REF!
 | #REF! | #REF!
 | #REF! | #REF!
 | #REF! | #REF!
 | #REF! | #REF!
 | #REF! | #REF!
 | #REF! | #REF!
 | #REF! | #REF!
 | #REF! | #REF!
 | #REF! | #REF!
 | #REF! | #REF!
 | #REF! | #REF!
 | #REF! | #REF!
 | #REF! | #REF!
 | #REF! | #REF!
 | #REF! | #REF!
 | #REF! | #REF!
 | #REF! | #REF!
 | #REF! | #REF!
 | #REF! | #REF!
 | #REF! | #REF!
 | #REF! | #REF!
 | #REF! | #REF!
 | #REF! | #REF!
 | #REF! | #REF!
 | #REF! | #REF!
 | #REF! | #REF!
 | #REF! | #REF!
 | #REF! | #REF!
 | #REF! | #REF!
 | #REF! | #REF!
 | #REF! | #REF!
 | #REF! | #REF!
 | #REF! | #REF!
 | #REF! | #REF!
 | #REF! | #REF!
 | #REF! | #REF!
 | #REF! | #REF!
 | #REF! | #REF!
 | #REF! | #REF!
 | #REF! | #REF!
 | #REF! | #REF!
 | #REF! | #REF!
 | #REF! | #REF!
 | #REF! | #REF!
 | #REF! | #REF!
 | #REF! | #REF!
 | #REF! | #REF!
 | #REF! | #REF!
 | #REF! | #REF!
 | #REF! | #REF!
 | #REF! | #REF!
 | #REF! | #REF!
 | #REF! | #REF!
 | #REF! | #REF!
 | #REF! | #REF!
 | #REF! | #REF!
 | #REF! | #REF!
 | #REF! | #REF!
 | #REF! | #REF!
 | #REF! | #REF!
 | #REF! | #REF!
 | #REF! | #REF!
 | #REF! | #REF!
 | #REF! | #REF!
 | #REF! | #REF!
 | #REF! | #REF!
 | #REF! | #REF!
 | #REF! | #REF!
 | #REF! | #REF!
 | #REF! | #REF!
 | #REF! | #REF!
 | #REF! | #REF!
 | #REF! | #REF!
 | #REF! | #REF!
 | #REF! | #REF!
 | #REF! | #REF!
 | #REF! | #REF!
 | #REF! | #REF!
 | #REF! | #REF!
 | #REF! | #REF!
 | #REF! | #REF!
 | #REF! | #REF!
 | #REF! | #REF!
 | #REF! | #REF!
 | #REF! | #REF!
 | #REF! | #REF!
 | #REF! | #REF!
 | #REF! | #REF!
 | #REF! | #REF!
 | #REF! | #REF!
 | #REF! | #REF!
 | #REF! | #REF!
 | #REF! | #REF!
 | #REF! | #REF!
 | #REF! | #REF!
 | #REF! | #REF!
 | #REF! | #REF!
 | #REF! | #REF!
 | #REF! | #REF!
 | #REF! | #REF!
 | #REF! | #REF!
 | #REF! | #REF!
 | #REF! | #REF!
 | #REF! | #REF!
 | #REF! | #REF!
 | #REF! | #REF!
 | #REF! | #REF!
 | #REF! | #REF!
 | #REF! | #REF!
 | #REF! | #REF!
 | #REF! | #REF!
 | #REF! | #REF!
 | #REF! | #REF!
 | #REF! | #REF!
 | #REF! | #REF!
 | #REF! | #REF!
 | #REF! | #REF!
 | #REF! | #REF!
 | #REF! | #REF!
 | #REF! | #REF!
 | #REF! | #REF!
 | #REF! | #REF!
 | #REF! | #REF!
 | #REF! | #REF!
 | #REF! | #REF!
 | #REF! | #REF!
 | #REF! | #REF!
 | #REF! | #REF!
 | #REF! | #REF!
 | #REF! | #REF!
 | #REF! | #REF!
 | #REF! | #REF!
 | #REF! | #REF!
 | #REF! | #REF!
 | #REF! | #REF!
 | #REF! | #REF!
 | #REF! | #REF!
 | #REF! | #REF!
 | #REF! | #REF!
 | #REF! | #REF!
 | #REF! | #REF!
 | #REF! | #REF!
 | #REF! | #REF!
 | #REF! | #REF!
 | #REF! | #REF!
 | #REF! | #REF!
 | #REF! | #REF!
 | #REF! | #REF!
 | #REF! | #REF!
 | #REF! | #REF!
 | #REF! | #REF!
 | #REF! | #REF!
 | #REF! | #REF!
 | #REF! | #REF!
 | #REF! | #REF!
 | #REF! | #REF!
 | #REF! | #REF!
 | #REF! | #REF!
 | #REF! | #REF!
 | #REF! | #REF!
 | #REF! | #REF!
 | #REF! | #REF!
 | #REF! | #REF!
 | #REF! | #REF!
 | #REF! | #REF!
 | #REF! | #REF!
 | #REF! | #REF!
 | #REF! | #REF!
 | #REF! | #REF!
 | #REF! | #REF!
 | #REF! | #REF!
 | #REF! | #REF!
 | #REF! | #REF!
 | #REF! | #REF!
 | #REF! | #REF!
 | #REF! | #REF!
 | #REF! | #REF!
 | #REF! | #REF!
 | #REF! | #REF!
 | #REF! | #REF!
 | #REF! | #REF!
 | #REF! | #REF!
 | #REF! | #REF!
 | #REF! | #REF!
 | #REF! | #REF!
 | #REF! | #REF!
 | #REF! | #REF!
 | #REF! | #REF!
 | #REF! | #REF!
 | #REF! | #REF!
 | #REF! | #REF!
 | #REF! | #REF!
 | #REF! | #REF!
 | #REF! | #REF!
 | #REF! | #REF!
 | #REF! | #REF!
 | #REF! | #REF!
 | #REF! | #REF!
 | #REF! | #REF!
 | #REF! | #REF!
 | #REF! | #REF!
 | #REF! | #REF!
 | #REF! | #REF!
 | #REF! | #REF!
 | #REF! | #REF!
 | #REF! | #REF!
 | #REF! | #REF!
 | #REF! | #REF!
 | #REF! | #REF!
 | #REF! | #REF!
 | #REF! | #REF!
 | #REF! | #REF!
 | #REF! | #REF!
 | #REF! | #REF!
 | #REF! | #REF!
 | #REF! | #REF!
 | #REF! | #REF!
 | #REF! | #REF!
 | #REF! | #REF!
 | #REF! | #REF!
 | #REF! | #REF!
 | #REF! | #REF!
 | #REF! | #REF!
 | #REF! | #REF!
 | #REF! | #REF!
 | #REF! | #REF!
 | #REF! | #REF!
 | #REF! | #REF!
 | #REF! | #REF!
 | #REF! | #REF!
 | #REF! | #REF!
 | #REF! | #REF!
 | #REF! | #REF!
 | #REF! | #REF!
 | #REF! | #REF!
 | #REF! | #REF!
 | #REF! | #REF!
 | #REF! | #REF!
 | #REF! | #REF!
 | #REF! | #REF!
 | #REF! | #REF!
 | #REF! | #REF!
 | #REF! | #REF!
 | #REF! | #REF!
 | #REF! | #REF!
 | #REF! | #REF!
 | #REF! | #REF!
 | #REF! | #REF!
 | #REF! | #REF!
 | #REF! | #REF!
 | #REF! | #REF!
 | #REF! | #REF!
 | #REF! | #REF!
 | #REF! | #REF!
 | #REF! | #REF!
 | #REF! | #REF!
 | #REF! | #REF!
 | #REF! | #REF!
 | #REF! | #REF!
 | #REF! | #REF!
 | #REF! | #REF!
 | #REF! | #REF!
 | #REF! | #REF!
 | #REF! | #REF!
 | #REF! | #REF!
 | #REF! | #REF!
 | #REF! | #REF!
 | #REF! | #REF!
 | #REF! | #REF!
 | #REF! | #REF!
 | #REF! | #REF!
 | #REF! | #REF!
 | #REF! | #REF!
 | #REF! | #REF!
 | #REF! | #REF!
 | #REF! | #REF!
 | #REF! | #REF!
 | #REF! | #REF!
 | #REF! | #REF!
 | #REF! | #REF!
 | #REF! | #REF!
 | #REF! | #REF!
 | #REF! | #REF!
 | #REF! | #REF!
 | #REF! | #REF!
 | #REF! | #REF!
 | #REF! | #REF!
 | #REF! | #REF!
 | #REF! | #REF!
 | #REF! | #REF!
 | #REF! | #REF!
 | #REF! | #REF!
 | #REF! | #REF!
 | #REF! | #REF!
 | #REF! | #REF!
 | #REF! | #REF!
 | #REF! | #REF!
 | #REF! | #REF!
 | #REF! | #REF!
 | #REF! | #REF!
 | #REF! | #REF!
 | #REF! | #REF!
 | #REF! | #REF!
 | #REF! | #REF!
 | #REF! | #REF!
 | #REF! | #REF!
 | #REF! | #REF!
 | #REF! | #REF!
 | #REF! | #REF!
 | #REF! | #REF!
 | #REF! | #REF!
 | #REF! | #REF!
 | #REF! | #REF!
 | #REF! | #REF!
 | #REF! | #REF!
 | #REF! | #REF!
 | #REF! | #REF!
 | #REF! | #REF!
 | #REF! | #REF!
 | #REF! | #REF!
 | #REF! | #REF!
 | #REF! | #REF!
 | #REF! | #REF!
 | #REF! | #REF!
 | #REF! | #REF!
 | #REF! | #REF!
 | #REF! | #REF!
 | #REF! | #REF!
 | #REF! | #REF!
 | #REF! | #REF!
 | #REF! | #REF!
 | #REF! | #REF!
 | #REF! | #REF!
 | #REF! | #REF!
 | #REF! | #REF!
 | #REF! | #REF!
 | #REF! | #REF!
 | #REF! | #REF!
 | #REF! | #REF!
 | #REF! | #REF!
 | #REF! | #REF!
 | #REF! | #REF!
 | #REF! | #REF!
 | #REF! | #REF!
 | #REF! | #REF!
 | #REF! | #REF!
 | #REF! | #REF!
 | #REF! | #REF!
 | #REF! | #REF!
 | #REF! | #REF!
 | #REF! | #REF!
 | #REF! | #REF!
 | #REF! | #REF!
 | #REF! | #REF!
 | #REF! | #REF!
 | #REF! | #REF!
 | #REF! | #REF!
 | #REF! | #REF!
 | #REF! | #REF!
 | #REF! | #REF!
 | #REF! | #REF!
 | #REF! | #REF!
 | #REF! | #REF!
 | #REF! | #REF!
 | #REF! | #REF!
 | #REF! | #REF!
 | #REF! | #REF!
 | #REF! | #REF!
 | #REF! | #REF!
 | #REF! | #REF!
 | #REF! | #REF!
 | #REF! | #REF!
 | #REF! | #REF!
 | #REF! | #REF!
 | #REF! | #REF!
 | #REF! | #REF!
 | #REF! | #REF!
 | #REF! | #REF!
 | #REF! | #REF!
 | #REF! | #REF!
 | #REF! | #REF!
 | #REF! | #REF!
 | #REF! | #REF!
 | #REF! | #REF!
 | #REF! | #REF!
 | #REF! | #REF!
 | #REF! | #REF!
 | #REF! | #REF!
 | #REF! | #REF!
 | #REF! | #REF!
 | #REF! | #REF!
 | #REF! | #REF!
 | #REF! | #REF!
 | #REF! | #REF!
 | #REF! | #REF!
 | #REF! | #REF!
 | #REF! | #REF!
 | #REF! | #REF!
 | #REF! | #REF!
 | #REF! | #REF!
 | #REF! | #REF!
 | #REF! | #REF!
 | #REF! | #REF!
 | #REF! | #REF!
 | #REF! | #REF!
 | #REF! | #REF!
 | #REF! | #REF!
 | #REF! | #REF!
 | #REF! | #REF!
 | #REF! | #REF!
 | #REF! | #REF!
 | #REF! | #REF!
 | #REF! | #REF!
 | #REF! | #REF!
 | #REF! | #REF!
 | #REF! | #REF!
 | #REF! | #REF!
 | #REF! | #REF!
 | #REF! | #REF!
 | #REF! | #REF!
 | #REF! | #REF!
 | #REF! | #REF!
 | #REF! | #REF!
 | #REF! | #REF!
 | #REF! | #REF!
 | #REF! | #REF!
 | #REF! | #REF!
 | #REF! | #REF!
 | #REF! | #REF!
 | #REF! | #REF!
 | #REF! | #REF!
 | #REF! | #REF!
 | #REF! | #REF!
 | #REF! | #REF!
 | #REF! | #REF!
 | #REF! | #REF!
 | #REF! | #REF!
 | #REF! | #REF!
 | #REF! | #REF!
 | #REF! | #REF!
 | #REF! | #REF!
 | #REF! | #REF!
 | #REF! | #REF!
 | #REF! | #REF!
 | #REF! | #REF!
 | #REF! | #REF!
 | #REF! | #REF!
 | #REF! | #REF!
 | #REF! | #REF!
 | #REF! | #REF!
 | #REF! | #REF!
 | #REF! | #REF!
 | #REF! | #REF!
 | #REF! | #REF!
 | #REF! | #REF!
 | #REF! | #REF!
 | #REF! | #REF!
 | #REF! | #REF!
 | #REF! | #REF!
 | #REF! | #REF!
 | #REF! | #REF!
 | #REF! | #REF!
 | #REF! | #REF!
 | #REF! | #REF!
 | #REF! | #REF!
 | #REF! | #REF!
 | #REF! | #REF!
 | #REF! | #REF!
 | #REF! | #REF!
 | #REF! | #REF!
 | #REF! | #REF!
 | #REF! | #REF!
 | #REF! | #REF!
 | #REF! | #REF!
 | #REF! | #REF!
 | #REF! | #REF!
 | #REF! | #REF!
 | #REF! | #REF!
 | #REF! | #REF!
 | #REF! | #REF!
 | #REF! | #REF!
 | #REF! | #REF!
 | #REF! | #REF!
 | #REF! | #REF!
 | #REF! | #REF!
 | #REF! | #REF!
 | #REF! | #REF!
 | #REF! | #REF!
 | #REF! | #REF!
 | #REF! | #REF!
 | #REF! | #REF!
 | #REF! | #REF!
 | #REF! | #REF!
 | #REF! | #REF!
 | #REF! | #REF!
 | #REF! | #REF!
 | #REF! | #REF!
 | #REF! | #REF!
 | #REF! | #REF!
 | #REF! | #REF!
 | #REF! | #REF!
 | #REF! | #REF!
 | #REF! | #REF!
 | #REF! | #REF!
 | #REF! | #REF!
 | #REF! | #REF!
 | #REF! | #REF!
 | #REF! | #REF!
 | #REF! | #REF!
 | #REF! | #REF!
 | #REF! | #REF!
 | #REF! | #REF!
 | #REF! | #REF!
 | #REF! | #REF!
 | #REF! | #REF!
 | #REF! | #REF!
 | #REF! | #REF!
 | #REF! | #REF!
 | #REF! | #REF!
 | #REF! | #REF!
 | #REF! | #REF!
 | #REF! | #REF!
 | #REF! | #REF!
 | #REF! | #REF!
 | #REF! | #REF!
 | #REF! | #REF!
 | #REF! | #REF!
 | #REF! | #REF!
 | #REF! | #REF!
 | #REF! | #REF!
 | #REF! | #REF!
 | #REF! | #REF!
 | #REF! | #REF!
 | #REF! | #REF!
 | #REF! | #REF!
 | #REF! | #REF!
 | #REF! | #REF!
 | #REF! | #REF!
 | #REF! | #REF!
 | #REF! | #REF!
 | #REF! | #REF!
 | #REF! | #REF!
 | #REF! | #REF!
 | #REF! | #REF!
 | #REF! | #REF!
 | #REF! | #REF!
 | #REF! | #REF!
 | #REF! | #REF!
 | #REF! | #REF!
 | #REF! | #REF!
 | #REF! | #REF!
 | #REF! | #REF!
 | #REF! | #REF!
 | #REF! | #REF!
 | #REF! | #REF!
 | #REF! | #REF!
 | #REF! | #REF!
 | #REF! | #REF!
 | #REF! | #REF!
 | #REF! | #REF!
 | #REF! | #REF!
 | #REF! | #REF!
 | #REF! | #REF!
 | #REF! | #REF!
 | #REF! | #REF!
 | #REF! | #REF!
 | #REF! | #REF!
 | #REF! | #REF!
 | #REF! | #REF!
 | #REF! | #REF!
 | #REF! | #REF!
 | #REF! | #REF!
 | #REF! | #REF!
 | #REF! | #REF!
 | #REF! | #REF!
 | #REF! | #REF!
 | #REF! | #REF!
 | #REF! | #REF!
 | #REF! | #REF!
 | #REF! | #REF!
 | #REF! | #REF!
 | #REF! | #REF!
 | #REF! | #REF!
 | #REF! | #REF!
 | #REF! | #REF!
 | #REF! | #REF!
 | #REF! | #REF!
 | #REF! | #REF!
 | #REF! | #REF!
 | #REF! | #REF!
 | #REF! | #REF!
 | #REF! | #REF!
 | #REF! | #REF!
 | #REF! | #REF!
 | #REF! | #REF!
 | #REF! | #REF!
 | #REF! | #REF!
 | #REF! | #REF!
 | #REF! | #REF!
 | #REF! | #REF!
 | #REF! | #REF!
 | #REF! | #REF!
 | #REF! | #REF!
 | #REF! | #REF!
 | #REF! | #REF!
 | #REF! | #REF!
 | #REF! | #REF!
 | #REF! | #REF!
 | #REF! | #REF!
 | #REF! | #REF!
 | #REF! | #REF!
 | #REF! | #REF!
 | #REF! | #REF!
 | #REF! | #REF!
 | #REF! | #REF!
 | #REF! | #REF!
 | #REF! | #REF!
 | #REF! | #REF!
 | #REF! | #REF!
 | #REF! | #REF!
 | #REF! | #REF!
 | #REF! | #REF!
 | #REF! | #REF!
 | #REF! | #REF!
 | #REF! | #REF!
 | #REF! | #REF!
 | #REF! | #REF!
 | #REF! | #REF!
 | #REF! | #REF!
 | #REF! | #REF!
 | #REF! | #REF!
 | #REF! | #REF!
 | #REF! | #REF!
 | #REF! | #REF!
 | #REF! | #REF!
 | #REF! | #REF!
 | #REF! | #REF!
 | #REF! | #REF!
 | #REF! | #REF!
 | #REF! | #REF!
 | #REF! | #REF!
 | #REF! | #REF!
 | #REF! | #REF!
 | #REF! | #REF!
 | #REF! | #REF!
 | #REF! | #REF!
 | #REF! | #REF!
 | #REF! | #REF!
 | #REF! | #REF!
 | #REF! | #REF!
 | #REF! | #REF!
 | #REF! | #REF!
 | #REF! | #REF!
 | #REF! | #REF!
 | #REF! | #REF!
 | #REF! | #REF!
 | #REF! | #REF!
 | #REF! | #REF!
 | #REF! | #REF!
 | #REF! | #REF!
 | #REF! | #REF!
 | #REF! | #REF!
 | #REF! | #REF!
 | #REF! | #REF!
 | #REF! | #REF!
 | #REF! | #REF!
 | #REF! | #REF!
 | #REF! | #REF!
 | #REF! | #REF!
 | #REF! | #REF!
 | #REF! | #REF!
 | #REF! | #REF!
 | #REF! | #REF!
 | #REF! | #REF!
 | #REF! | #REF!
 | #REF! | #REF!
 | #REF! | #REF!
 | #REF! | #REF!
 | #REF! | #REF!
 | #REF! | #REF!
 | #REF! | #REF!
 | #REF! | #REF!
 | #REF! | #REF!
 | #REF! | #REF!
 | #REF! | #REF!
 | #REF! | #REF!
 | #REF! | #REF!
 | #REF! | #REF!
 | #REF! | #REF!
 | #REF! | #REF!
 | #REF! | #REF!
 | #REF! | #REF!
 | #REF! | #REF!
 | #REF! | #REF!
 | #REF! | #REF!
 | #REF! | #REF!
 | #REF! | #REF!
 | #REF! | #REF!
 | #REF! | #REF!
 | #REF! | #REF!
 | #REF! | #REF!
 | #REF! | #REF!
 | #REF! | #REF!
 | #REF! | #REF!
 | #REF! | #REF!
 | #REF! | #REF!
 | #REF! | #REF!
 | #REF! | #REF!
 | #REF! | #REF!
 | #REF! | #REF!
 | #REF! | #REF!
 | #REF! | #REF!
 | #REF! | #REF!
 | #REF! | #REF!
 | #REF! | #REF!
 | #REF! | #REF!
 | #REF! | #REF!
 | #REF! | #REF!
 | #REF! | #REF!
 | #REF! | #REF!
 | #REF! | #REF!
 | #REF! | #REF!
 | #REF! | #REF!
 | #REF! | #REF!
 | #REF! | #REF!
 | #REF! | #REF!
 | #REF! | #REF!
 | #REF! | #REF!
 | #REF! | #REF!
 | #REF! | #REF!
 | #REF! | #REF!
 | #REF! | #REF!
 | #REF! | #REF!
 | #REF! | #REF!
 | #REF! | #REF!
 | #REF! | #REF!
 | #REF! | #REF!
 | #REF! | #REF!
 | #REF! | #REF!
 | #REF! | #REF!
 | #REF! | #REF!
 | #REF! | #REF!
 | #REF! | #REF!
 | #REF! | #REF!
 | #REF! | #REF!
 | #REF! | #REF!
 | #REF! | #REF!
 | #REF! | #REF!
 | #REF! | #REF!
 | #REF! | #REF!
 | #REF! | #REF!
 | #REF! | #REF!
 | #REF! | #REF!
 | #REF! | #REF!
 | #REF! | #REF!
 | #REF! | #REF!
 | #REF! | #REF!
 | #REF! | #REF!
 | #REF! | #REF!
 | #REF! | #REF!
 | #REF! | #REF!
 | #REF! | #REF!
 | #REF! | #REF!
 | #REF! | #REF!
 | #REF! | #REF!
 | #REF! | #REF!
 | #REF! | #REF!
 | #REF! | #REF!
 | #REF! | #REF!
 | #REF! | #REF!
 | #REF! | #REF!
 | #REF! | #REF!
 | #REF! | #REF!
 | #REF! | #REF!
 | #REF! | #REF!
 | #REF! | #REF!
 | #REF! | #REF!
 | #REF! | #REF!
 | #REF! | #REF!
 | #REF! | #REF!
 | #REF! | #REF!
 | #REF! | #REF!
 | #REF! | #REF!
 | #REF! | #REF!
 | #REF! | #REF!
 | #REF! | #REF!
 | #REF! | #REF!
 | #REF! | #REF!
 | #REF! | #REF!
 | #REF! | #REF!
 | #REF! | #REF!
 | #REF! | #REF!
 | #REF! | #REF!
 | #REF! | #REF!
 | #REF! | #REF!
 | #REF! | #REF!
 | #REF! | #REF!
 | #REF! | #REF!
 | #REF! | #REF!
 | #REF! | #REF!
 | #REF! | #REF!
 | #REF! | #REF!
 | #REF! | #REF!
 | #REF! | #REF!
 | #REF! | #REF!
 | #REF! | #REF!
 | #REF! | #REF!
 | #REF! | #REF!
 | #REF! | #REF!
 | #REF! | #REF!
 | #REF! | #REF!
 | #REF! | #REF!
 | #REF! | #REF!
 | #REF! | #REF!
 | #REF! | #REF!
 | #REF! | #REF!
 | #REF! | #REF!
 | #REF! | #REF!
 | #REF! | #REF!
 | #REF! | #REF!
 | #REF! | #REF!
 | #REF! | #REF!
 | #REF! | #REF!
 | #REF! | #REF!
 | #REF! | #REF!
 | #REF! | #REF!
 | #REF! | #REF!
 | #REF! | #REF!
 | #REF! | #REF!
 | #REF! | #REF!
 | #REF! | #REF!
 | #REF! | #REF!
 | #REF! | #REF!
 | #REF! | #REF!
 | #REF! | #REF!
 | #REF! | #REF!
 | #REF! | #REF!
 | #REF! | #REF!
 | #REF! | #REF!
 | #REF! | #REF!
 | #REF! | #REF!
 | #REF! | #REF!
 | #REF! | #REF!
 | #REF! | #REF!
 | #REF! | #REF!
 | #REF! | #REF!
 | #REF! | #REF!
 | #REF! | #REF!
 | #REF! | #REF!
 | #REF! | #REF!
 | #REF! | #REF!
 | #REF! | #REF!
 | #REF! | #REF!
 | #REF! | #REF!
 | #REF! | #REF!
 | #REF! | #REF!
 | #REF! | #REF!
 | #REF! | #REF!
 | #REF! | #REF!
 | #REF! | #REF!
 | #REF! | #REF!
 | #REF! | #REF!
 | #REF! | #REF!
 | #REF! | #REF!
 | #REF! | #REF!
 | #REF! | #REF!
 | #REF! | #REF!
 | #REF! | #REF!
 | #REF! | #REF!
 | #REF! | #REF!
 | #REF! | #REF!
 | #REF! | #REF!
 | #REF! | #REF!
 | #REF! | #REF!
 | #REF! | #REF!
 | #REF! | #REF!
 | #REF! | #REF!
 | #REF! | #REF!

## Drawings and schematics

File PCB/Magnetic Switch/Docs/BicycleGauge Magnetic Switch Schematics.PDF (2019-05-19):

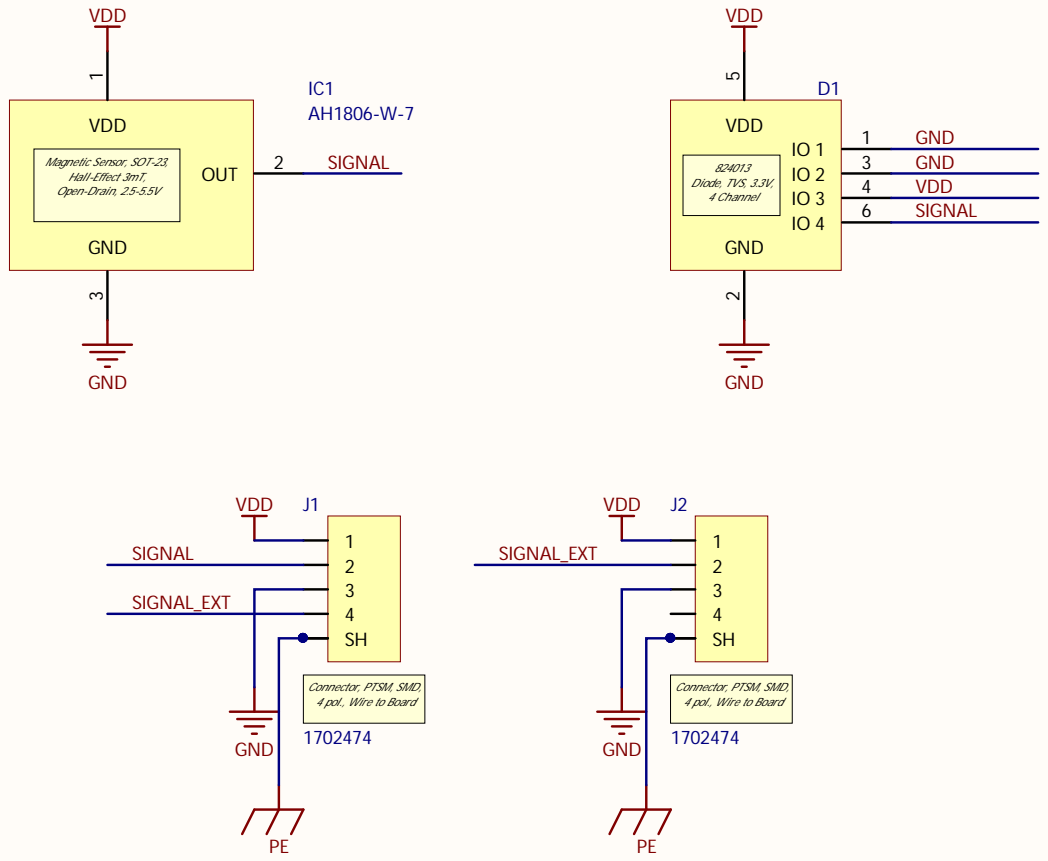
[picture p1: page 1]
1 GND; Diode, TVS, 3.3V, 4 Channel

Magnetic Sensor, SOT-23,
Hall-Effect 3mT,
Open-Drain, 2.5-5.5V

Connector, PTSM, SMD,
4 pol., Wire to Board

Title Bicycle Gauge Magnetic Switch | Drawn by: Sven Möller Approved by: -

Size: A4 | | Revision: v1.0 | Private --

Date: 19.05.2019 Time: 10:40:03 | | Sheet 1 of 1

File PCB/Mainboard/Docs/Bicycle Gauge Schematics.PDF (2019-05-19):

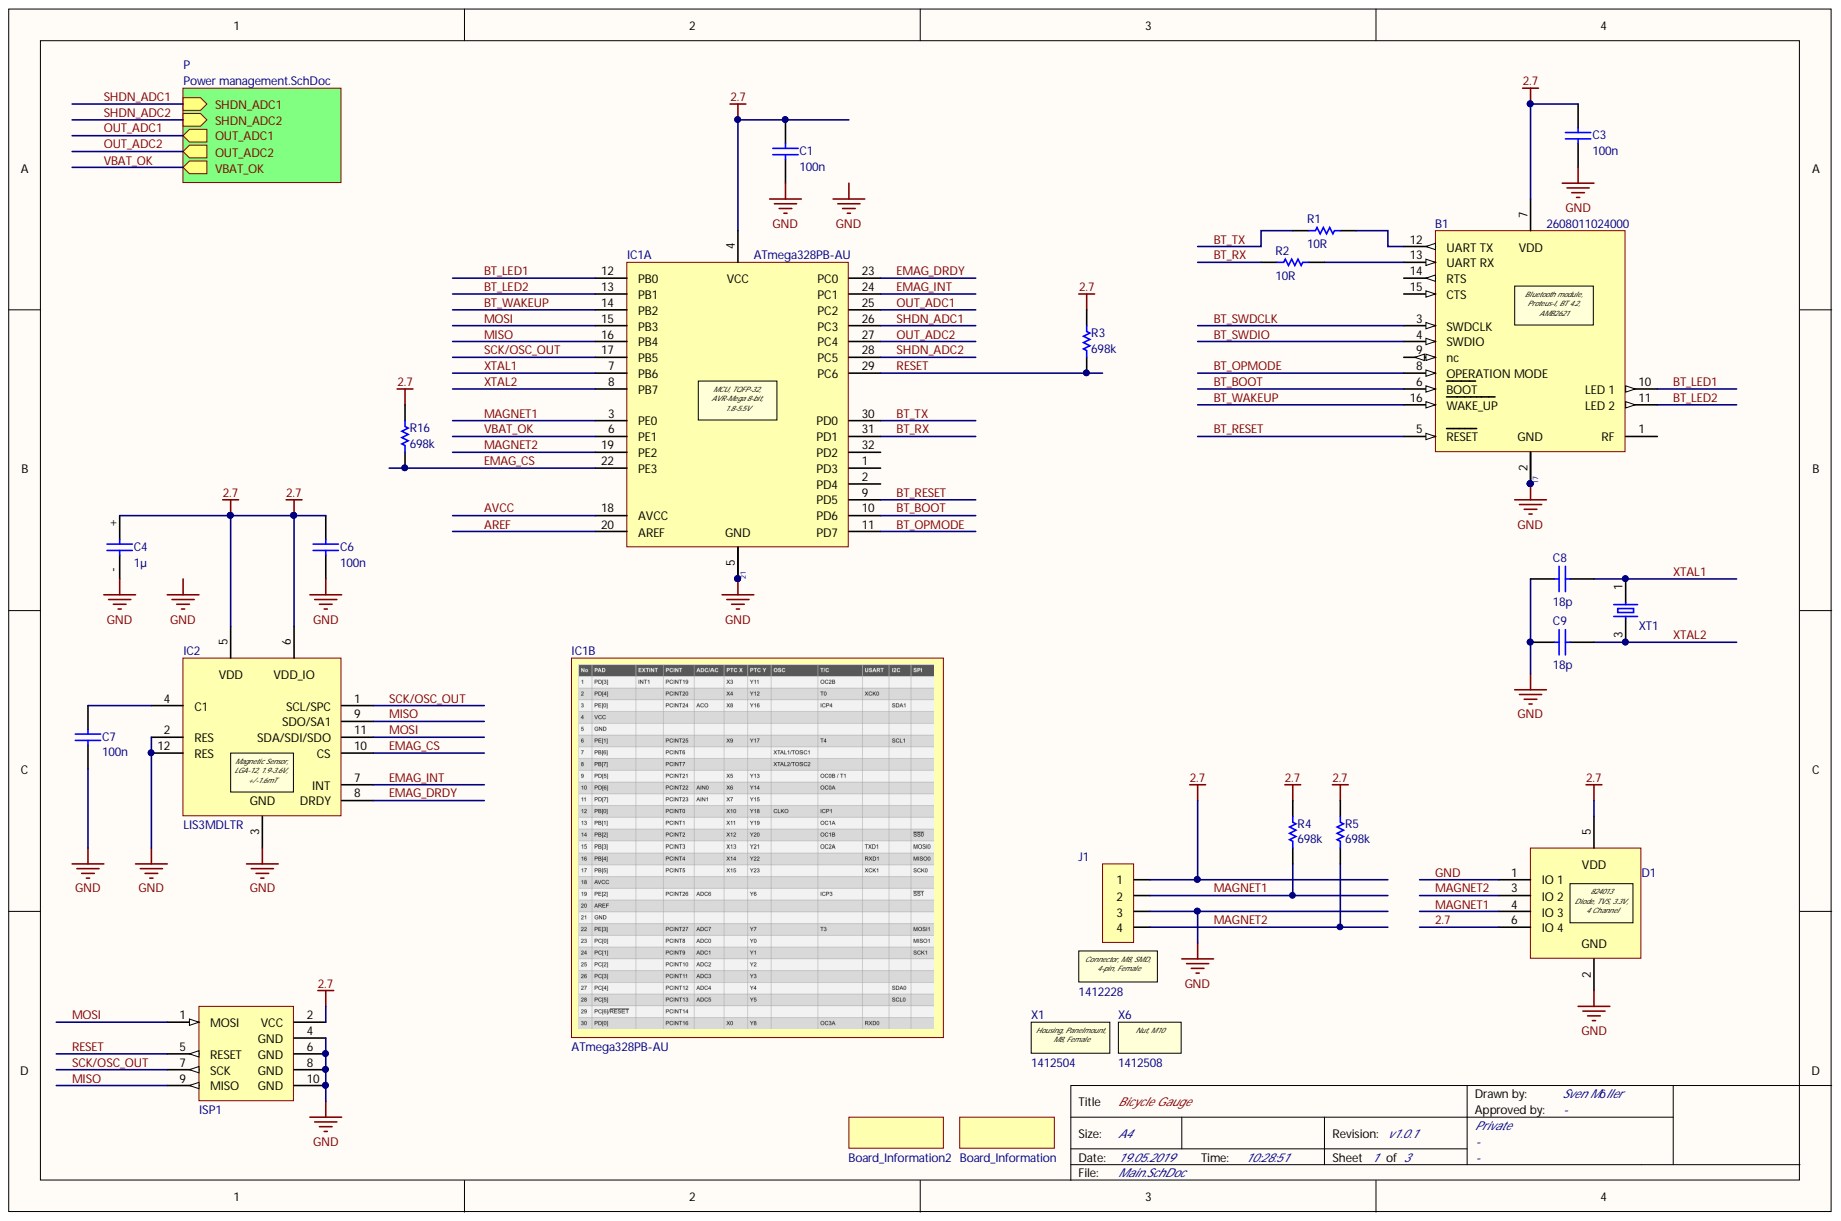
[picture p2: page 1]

Titl e Bicycle Gaug e | Dra wn by: Sven Möller Ap proved by: -

Si ze: A 4 | | Revi s i on: v1.0.1 | Priva te --

Date: 9.05.201 Ti me: 0:2 8:5 | | Sheet o f

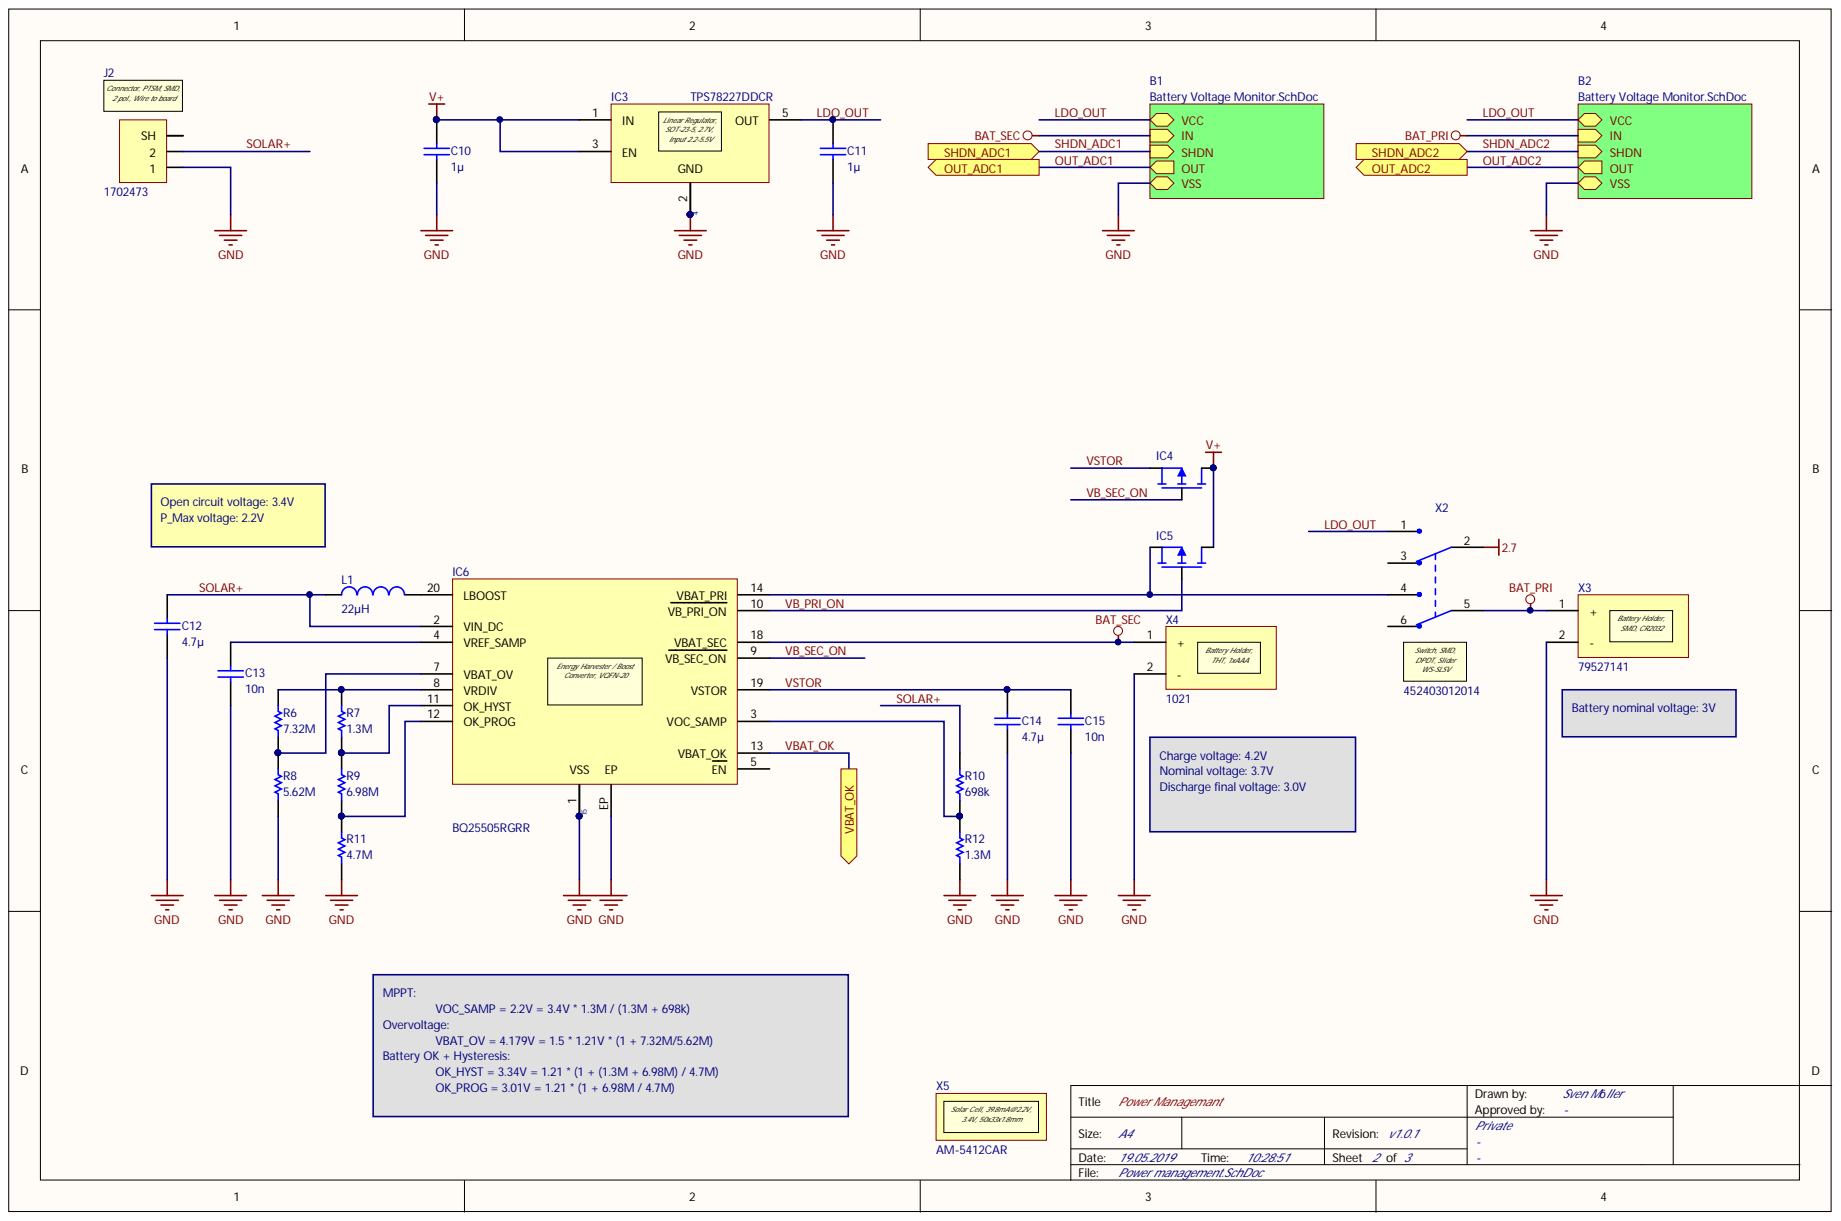
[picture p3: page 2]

Connector, PTSM, SMD,
2 pol., Wire to board

Battery Voltage Monitor.SchDoc

VRDIV 8

R7 | OK_PROG 12 VSS EP

Title Power Managemant | Drawn by: Sven Möller Approved by: -

Size: A4 | | Revision: v1.0.1 | Private --

19.05.2019 Time: 10:28:51 | | Sheet of 3

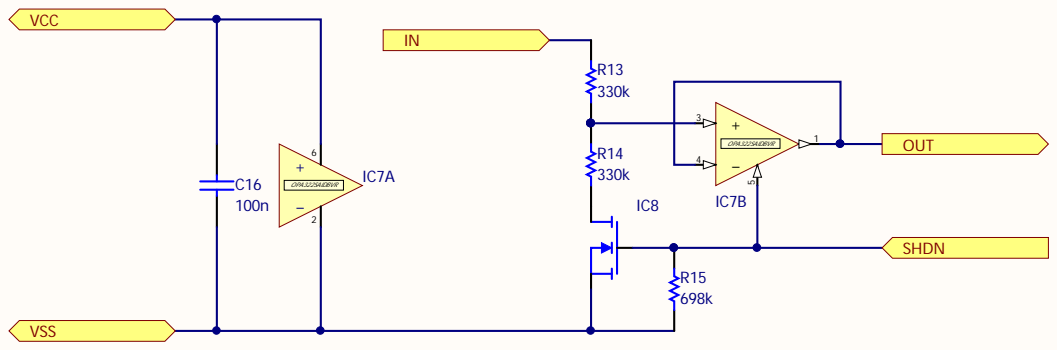
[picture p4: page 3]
PIC1602 COC16; PIIC706 COIC7A; PIIC704 COIC7B; PIIC705; PIIC703 PIR1301

Titl e Ba ttery Monito r | Dra wn by: Sven Möller Ap proved by: -

Si ze: A 4 | | Revi s i on: v1.0.1 | Priva te --

9.05.201 Ti me: 0:2 8:5 | | Sheet o f

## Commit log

2019-05-11 First version of mainboard
    [Battery Voltage Monitor.SchDoc, Bicycle Gauge.PrjPcb, Main.SchDoc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]
2019-05-19 Adding: - Schematic template - Schematics and BOM for Magnetic switches v1.0 - BOM for Mainboard Update: - Schematics for Mainboard (minimal design changes) v1.0.1
    [BOM_Assembly-Bicycle Gauge(Variant of Bicycle Gauge).xls, BOM_Assembly-BicycleGauge Magnetic Switch.xls, BOM_Order-Bicycle Gauge(Variant of Bicycle Gauge).xls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]
2019-05-25 Prototype PCB Design finished Fabrication files and 3D PDF added
    [Bicycle Gauge.PrjPcb, BicycleGauge Magnetic Switch.PrjPcb, PcbLib1.PcbLib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]
